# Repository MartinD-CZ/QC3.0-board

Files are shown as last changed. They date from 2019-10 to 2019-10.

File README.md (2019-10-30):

# QC3.0 board
*see the article [here](http://embedblog.eu/?p=504). Also available on [Tindie](https://www.tindie.com/products/martind/quick-charge-qc-30-buck-converter-board/).*
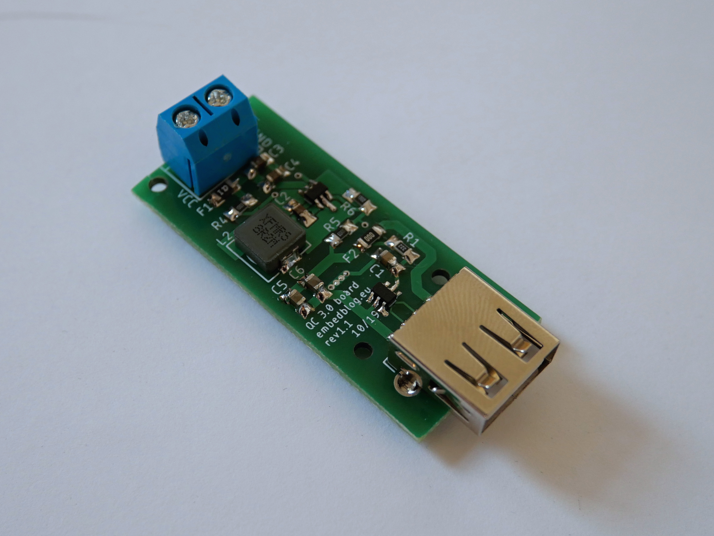
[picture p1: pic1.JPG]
A picture of the finished device


Board with a switching buck converter and a QC 3.0 class-A chip (it also supports FastCharge, DCP, and others).

## Features:
* HiSilicon Fast Charging Protocol (FCP), ie Huawei phones (tested)
* Qualcomm Quick Charge 2.0/3.0 Class A: up to 12 V Output Voltage (tested)
* USB DCP (shorting D+ Line to D-) per USB Battery Charging Specification, Revision 1.2 (tested)
* USB DCP (applying 2.7V on D+ Line and 2.7V on D- Line), ie Apple 12 W
* USB DCP (applying 1.2V on D+ and D- Lines)
* Chinese Telecommunication Industrial Standard YD/T 1591-2009 (whatever that is, I have not tested that)

## Specs:
* input voltage: 6 - 15 V, recommended 12 - 15 V
* input current: max 2 A
* output current: max 2 A
* efficiency (Vin = 12 V, Vout = 5 V, Iout = 1 A): 95 %
* efficiency (Vin = 12 V, Vout = 5 V, Iout = 2 A): 92 %
* quiescent current (no load connected, Vin = 12 V): 800 µA

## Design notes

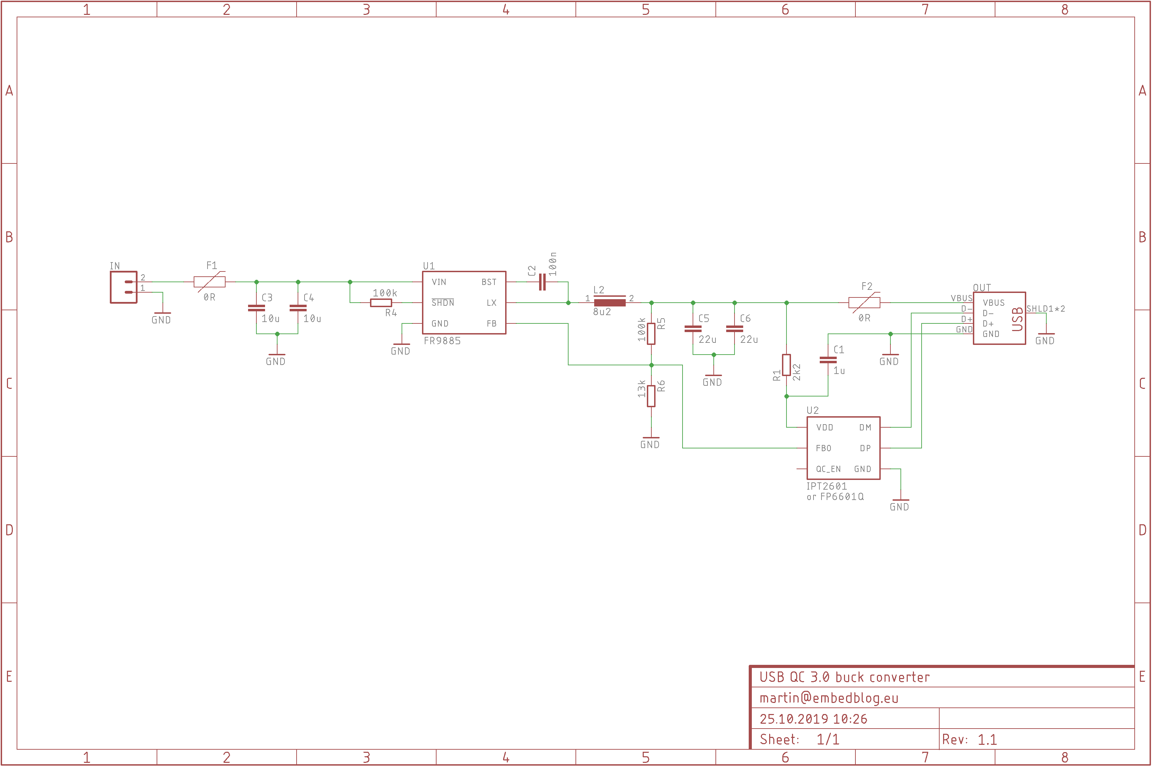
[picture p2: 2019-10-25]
schematics.png

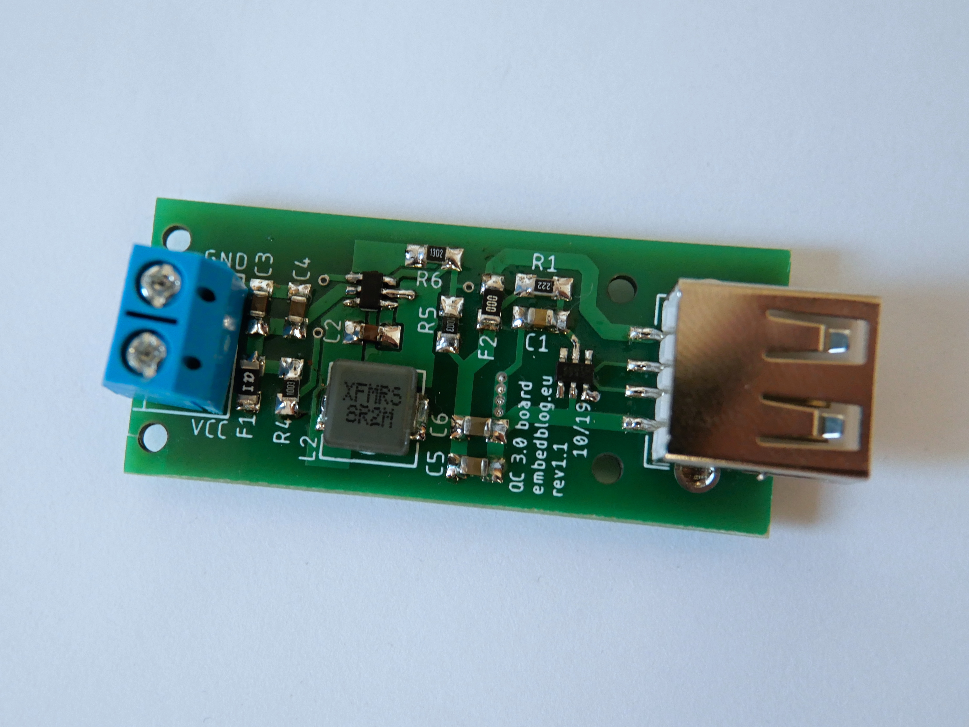
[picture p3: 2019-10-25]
pic2.JPG

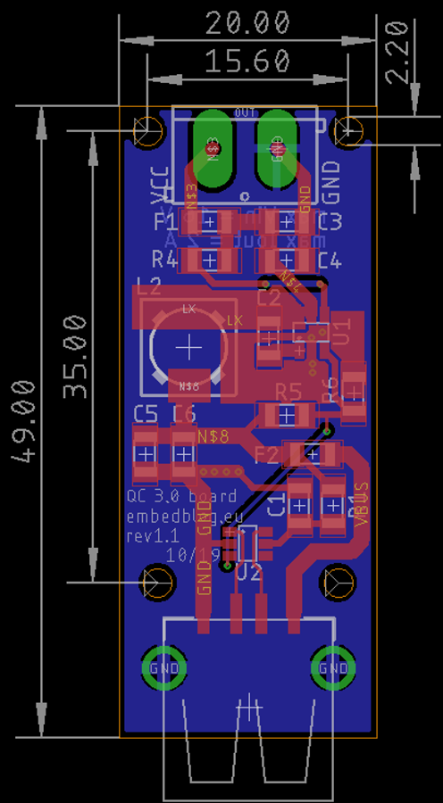
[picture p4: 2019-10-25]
board.png

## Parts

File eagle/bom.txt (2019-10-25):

Part Value                   Device                  Package             Description                                             
C1   1u                      C-EUC1206               C1206               CAPACITOR, European symbol                                                           
C2   100n                    C-EUC1206               C1206               CAPACITOR, European symbol                                                           
C3   10u/16V                 C-EUC1206               C1206               CAPACITOR, European symbol                                                          
C4   10u/16V                 C-EUC1206               C1206               CAPACITOR, European symbol                                                           
C5   22u/16V                 C-EUC1206               C1206               CAPACITOR, European symbol                                                           
C6   22u/16V                 C-EUC1206               C1206               CAPACITOR, European symbol                                                           
F1   0R                      PPTC_HALF-AMP           1206                Resettable Fuse PPTC                                  
F2   0R                      PPTC_HALF-AMP           1206                Resettable Fuse PPTC                                    
IN   5MM_SCREWTERMINAL_LARGE 5MM_SCREWTERMINAL_LARGE SCREWTERMINAL-5MM-2                                                                                      
L2   8u2                     DR73                    DR73                High Power Density, High Efficiency, Shielded Inductors           L                  
OUT  USB_A_REVERSED          USB_A_REVERSED          USB-A-S-SILK-FEMALE                                                                                      
R1   2k2                     R-EU_R1206              R1206               RESISTOR, European symbol                                                            
R4   100k                    R-EU_R1206              R1206               RESISTOR, European symbol                                                            
R5   100k                    R-EU_R1206              R1206               RESISTOR, European symbol                                                            
R6   13k                     R-EU_R1206              R1206               RESISTOR, European symbol                                                            
U1   FR9885                  FR9885                  SOT23-6                                                                                                  
U2   IPT2601                 IPT2601                 SOT23-6

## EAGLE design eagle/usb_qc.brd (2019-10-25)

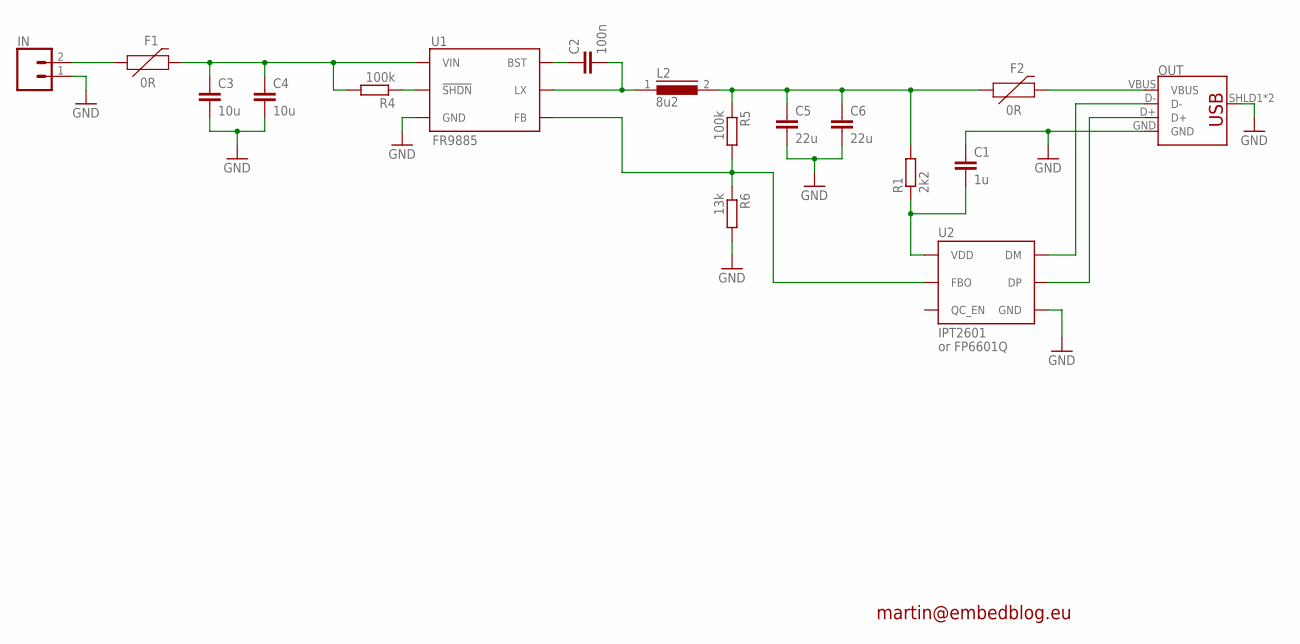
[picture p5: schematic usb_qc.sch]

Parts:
C1: 1u; C1206
C2: 100n; C1206
C3, C4: 10u; C1206
C5, C6: 22u; C1206
F1, F2: 0R; 1206
IN: 5MM_SCREWTERMINAL_LARGE; SCREWTERMINAL-5MM-2
L2: 8u2; DR73
OUT: USB_A_REVERSED; USB-A-S-SILK-FEMALE
R1: 2k2; R1206
R4, R5: 100k; R1206
R6: 13k; R1206
U1: FR9885; SOT23-6
U2: IPT2601; SOT23-6

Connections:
FB: R5.2, R6.1, U1.3 (FB), U2.3 (FBO)
GND: C1.1, C3.2, C4.2, C5.2, C6.2, IN.1, OUT.GND, OUT.SHLD1 (SHIELD), OUT.SHLD2 (SHIELD), R6.2, U1.2 (GND), U2.2 (GND)
LX: C2.2, L2.1, U1.6 (LX)
unnamed: OUT.D-, U2.6 (DM)
unnamed: OUT.D+, U2.1 (DP)
unnamed: F1.1, IN.2
unnamed: C3.1, C4.1, F1.2, R4.2, U1.5 (VIN)
unnamed: R4.1, U1.4 (!SHDN)
unnamed: C5.1, C6.1, F2.1, L2.2, R1.2, R5.1
unnamed: C1.2, R1.1, U2.5 (VDD)
unnamed: C2.1, U1.1 (BST)
VBUS: F2.2, OUT.VBUS

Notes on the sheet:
or FP6601Q
martin@embedblog.eu

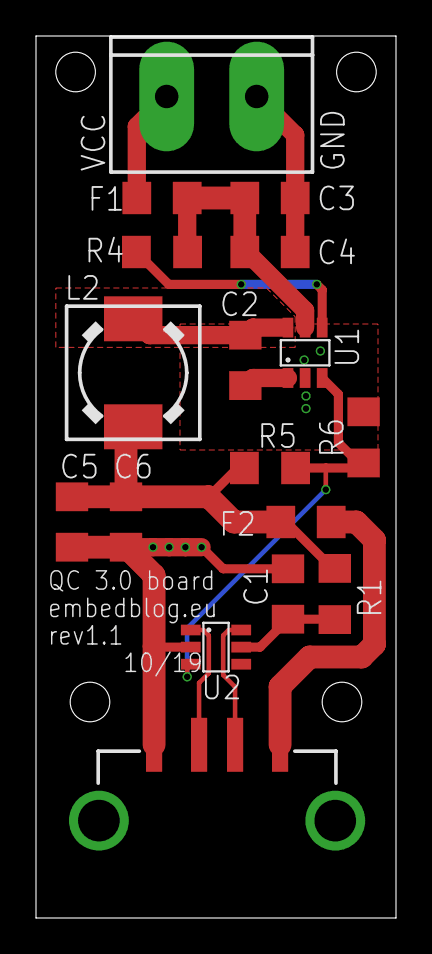
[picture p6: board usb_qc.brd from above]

Board: 2 copper layers, 20.0 x 49.0 mm, 17 parts (0 on the bottom side), 12 nets.

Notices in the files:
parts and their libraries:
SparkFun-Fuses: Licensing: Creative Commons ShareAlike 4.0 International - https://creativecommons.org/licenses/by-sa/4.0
